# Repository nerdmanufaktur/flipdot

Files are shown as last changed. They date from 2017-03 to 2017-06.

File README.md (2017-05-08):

# flipdot
Contains Code for running the flip-dot displays based on the driver pcb both from nerdmanufaktur.berlin

## Arduino 

Copy the folders from /Arduino to your local /Arduino/libraries folder and compile/upload the /Arduino/examples example Code. (Wemos for Wifi enabled ESP8266s and Arduino_HW for everything else)

The FLIPDOT library on an ESP8266 also provides an UDP-Server that listens on Port 1234 for data. It will accept DISPLAY_WIDTH*2 byte sized frames and render them immediatly.

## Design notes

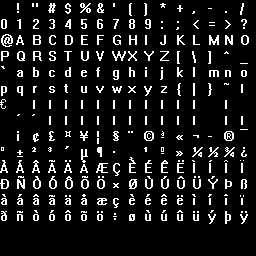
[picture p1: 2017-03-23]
font generation/ExportedFontBold.bmp

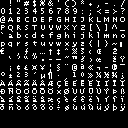
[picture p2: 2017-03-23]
font generation/ExportedFont8x8.bmp

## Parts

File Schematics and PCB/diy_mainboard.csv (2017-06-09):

Qty | Value | Device | Package | Parts | Description | DIGIKEY | MF | MPN | OC_FARNELL | OC_NEWARK
1 |  | ML34 | ML34 | SV1 | HARTING | AE11226-ND |  |  | unknown | unknown
1 |  | PINHD-1X5_2.54 | 1X05 | JP2 | PIN HEADER | A101735CT-ND
1 |  | PINHD-1X7_2.54 | 1X07 | JP1 | PIN HEADER | A101735CT-ND
1 |  | RN06 | RN-7 | RN2 | RESISTOR NETWORK | 4607X-101-472LF-ND |  |  | unknown | unknown
1 |  | W237-102 | W237-102 | X1 | WAGO SCREW CLAMP |  |  | 237-102 | unknown | 70K9898
5 | 100nF | C-EUC0603 | C0603 | C2, C4, C5, C6, C7 | CAPACITOR, European symbol | 478-5052-1-ND
2 | 100µF | CPOL-EU153CLV-0605 | 153CLV-0605 | C1, C3 | POLARIZED CAPACITOR, European symbol | 493-2203-1-ND
1 | 10k | R-EU_R0805 | R0805 | R2 | RESISTOR, European symbol | RMCF0805JT10K0CT-ND
2 | 1k | R-EU_R0805 | R0805 | R1, R3 | RESISTOR, European symbol | RMCF0805JT1K00CT-ND
3 | 74HC595D | 74HC595D | SO16 | IC2, IC3, IC4 | 8-bit SHIFT REGISTER, output latch | 568-2263-1-ND
1 | 7805DT | 7805DT | TO252 | IC1 | Positive VOLTAGE REGULATOR | MC7805CDTGOS-ND
1 | LL4148 | PMLL4150 | SOD80C | D1 | DIODE | LL4148FSCT-ND
1 | TBD62783AFGSO18 | TBD62783AFGSO18 | TBD62783AFG | U$1 |  | TBD62783AFGELCT-ND
1 | TBD62783AFGSO18 | TBD62783AFGSO18 | TBD62783AFG | U$2 |  | TBD62783AFGELCT-ND
1 | TIP131 | 2SC1306 | TO220BV | T1 | NPN Transistor Final RF Power Outupt
1 | ULN2803 | ULN2803 | TBD62783AFG | U$3 |  | 296-15777-1-ND

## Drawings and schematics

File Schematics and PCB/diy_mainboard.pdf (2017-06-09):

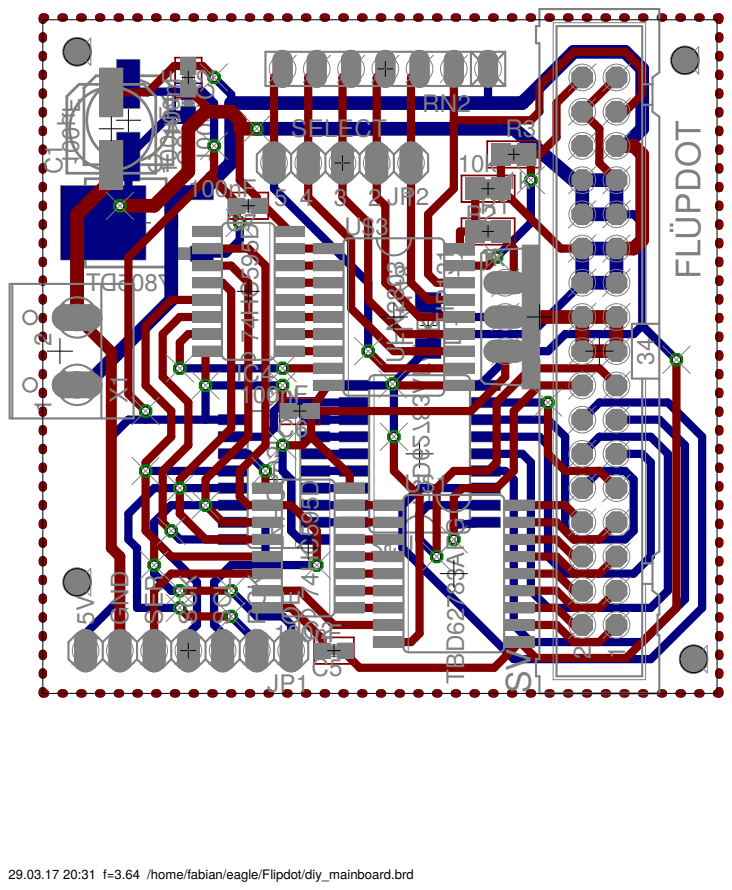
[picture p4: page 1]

29.03.17 20:31 f=3.64 /home/fabian/eagle/Flipdot/diy_mainboard.brd

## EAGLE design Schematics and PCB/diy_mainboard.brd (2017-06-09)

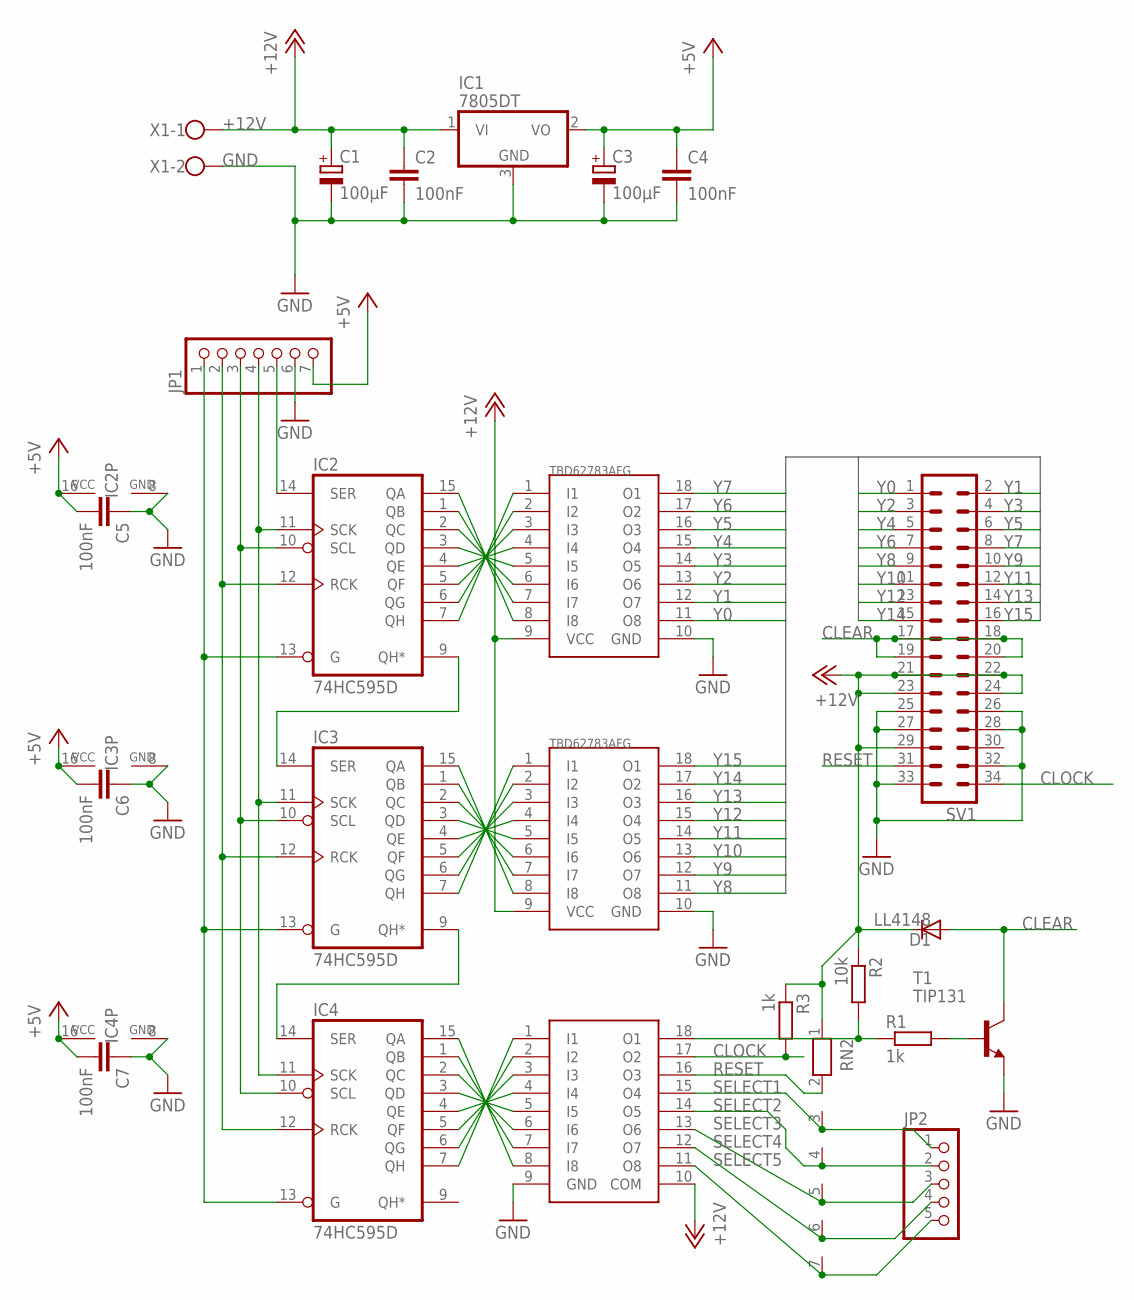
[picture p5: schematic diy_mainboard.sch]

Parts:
C1, C3: 100µF; 153CLV-0605; DIGIKEY 493-2203-1-ND
C2, C4, C5, C6, C7: 100nF; C0603; DIGIKEY 478-5052-1-ND
D1: LL4148; SOD80C; DIGIKEY LL4148FSCT-ND
IC1: 7805DT; TO252; DIGIKEY MC7805CDTGOS-ND
IC2, IC3, IC4: 74HC595D; SO16; DIGIKEY 568-2263-1-ND
JP1: PINHD-1X7; 1X07; DIGIKEY A101735CT-ND
JP2: PINHD-1X5; 1X05; DIGIKEY A101735CT-ND
R1, R3: 1k; R0805; DIGIKEY RMCF0805JT1K00CT-ND
R2: 10k; R0805; DIGIKEY RMCF0805JT10K0CT-ND
RN2: RN06; RN-7; DIGIKEY 4607X-101-472LF-ND
SV1: ML34; DIGIKEY AE11226-ND
T1: TIP131; TO220BV
U$1, U$2: TBD62783AFG; SO8-L; DIGIKEY TBD62783AFGELCT-ND
U$3: ULN2803; SO8-L; DIGIKEY 296-15777-1-ND
X1: W237-102

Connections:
+5V: C3.+, C4.1, C5.2, C6.2, C7.2, IC1.2 (VO), IC2.16 (VCC), IC3.16 (VCC), IC4.16 (VCC), JP1.7
+12V: C1.+, C2.1, D1.C, IC1.1 (VI), R2.1, R3.1, RN2.1, SV1.21, SV1.22, SV1.23, SV1.24, SV1.29, U$1.9 (VCC), U$2.9 (VCC), U$3.10 (COM), X1.1
CLEAR: D1.A, SV1.17, SV1.18, SV1.19, SV1.20, T1.2 (C)
CLOCK: R3.2, SV1.34, U$3.17 (O2)
GND: C1.-, C2.2, C3.-, C4.2, C5.1, C6.1, C7.1, IC1.3 (GND), IC2.8 (GND), IC3.8 (GND), IC4.8 (GND), JP1.6, SV1.25, SV1.26, SV1.27, SV1.28, SV1.32, SV1.33, T1.3 (E), U$1.10 (GND), U$2.10 (GND), U$3.9 (GND), X1.2
unnamed: IC2.15 (QA), U$1.8 (I8)
unnamed: IC2.1 (QB), U$1.7 (I7)
unnamed: IC2.2 (QC), U$1.6 (I6)
unnamed: IC2.3 (QD), U$1.5 (I5)
unnamed: IC2.4 (QE), U$1.4 (I4)
unnamed: IC2.5 (QF), U$1.3 (I3)
unnamed: IC2.6 (QG), U$1.2 (I2)
unnamed: IC2.7 (QH), U$1.1 (I1)
unnamed: IC3.15 (QA), U$2.8 (I8)
unnamed: IC3.1 (QB), U$2.7 (I7)
unnamed: IC3.2 (QC), U$2.6 (I6)
unnamed: IC3.3 (QD), U$2.5 (I5)
unnamed: IC3.4 (QE), U$2.4 (I4)
unnamed: IC3.5 (QF), U$2.3 (I3)
unnamed: IC3.6 (QG), U$2.2 (I2)
unnamed: IC3.7 (QH), U$2.1 (I1)
unnamed: IC2.9 (QH*), IC3.14 (SER)
unnamed: IC2.11 (SCK), IC3.11 (SCK), IC4.11 (SCK), JP1.4
unnamed: IC2.10 (SCL), IC3.10 (SCL), IC4.10 (SCL), JP1.3
unnamed: IC2.12 (RCK), IC3.12 (RCK), IC4.12 (RCK), JP1.2
unnamed: IC2.13 (G), IC3.13 (G), IC4.13 (G), JP1.1
unnamed: IC3.9 (QH*), IC4.14 (SER)
unnamed: IC4.15 (QA), U$3.8 (I8)
unnamed: IC4.1 (QB), U$3.7 (I7)
unnamed: IC4.2 (QC), U$3.6 (I6)
unnamed: IC4.3 (QD), U$3.5 (I5)
unnamed: IC4.4 (QE), U$3.4 (I4)
unnamed: IC4.5 (QF), U$3.3 (I3)
unnamed: IC4.6 (QG), U$3.2 (I2)
unnamed: IC4.7 (QH), U$3.1 (I1)
unnamed: R1.2, T1.1 (B)
unnamed: R1.1, R2.2, U$3.18 (O1)
unnamed: IC2.14 (SER), JP1.5
RESET: RN2.2, SV1.31, U$3.16 (O3)
SELECT1: JP2.1, RN2.3, U$3.15 (O4)
SELECT2: JP2.2, RN2.4, U$3.14 (O5)
SELECT3: JP2.3, RN2.5, U$3.13 (O6)
SELECT4: JP2.4, RN2.6, U$3.12 (O7)
SELECT5: JP2.5, RN2.7, U$3.11 (O8)
Y0: SV1.1, U$1.11 (O8)
Y1: SV1.2, U$1.12 (O7)
Y2: SV1.3, U$1.13 (O6)
Y3: SV1.4, U$1.14 (O5)
Y4: SV1.5, U$1.15 (O4)
Y5: SV1.6, U$1.16 (O3)
Y6: SV1.7, U$1.17 (O2)
Y7: SV1.8, U$1.18 (O1)
Y8: SV1.9, U$2.11 (O8)
Y9: SV1.10, U$2.12 (O7)
Y10: SV1.11, U$2.13 (O6)
Y11: SV1.12, U$2.14 (O5)
Y12: SV1.13, U$2.15 (O4)
Y13: SV1.14, U$2.16 (O3)
Y14: SV1.15, U$2.17 (O2)
Y15: SV1.16, U$2.18 (O1)

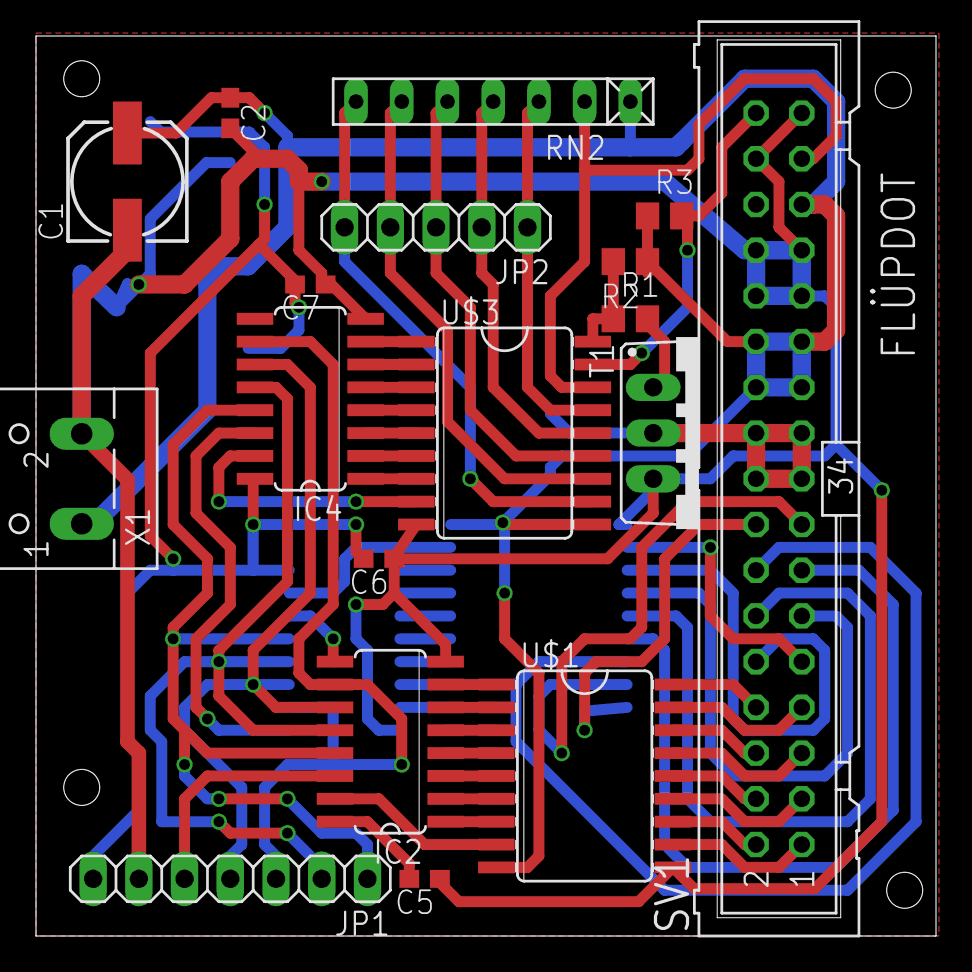
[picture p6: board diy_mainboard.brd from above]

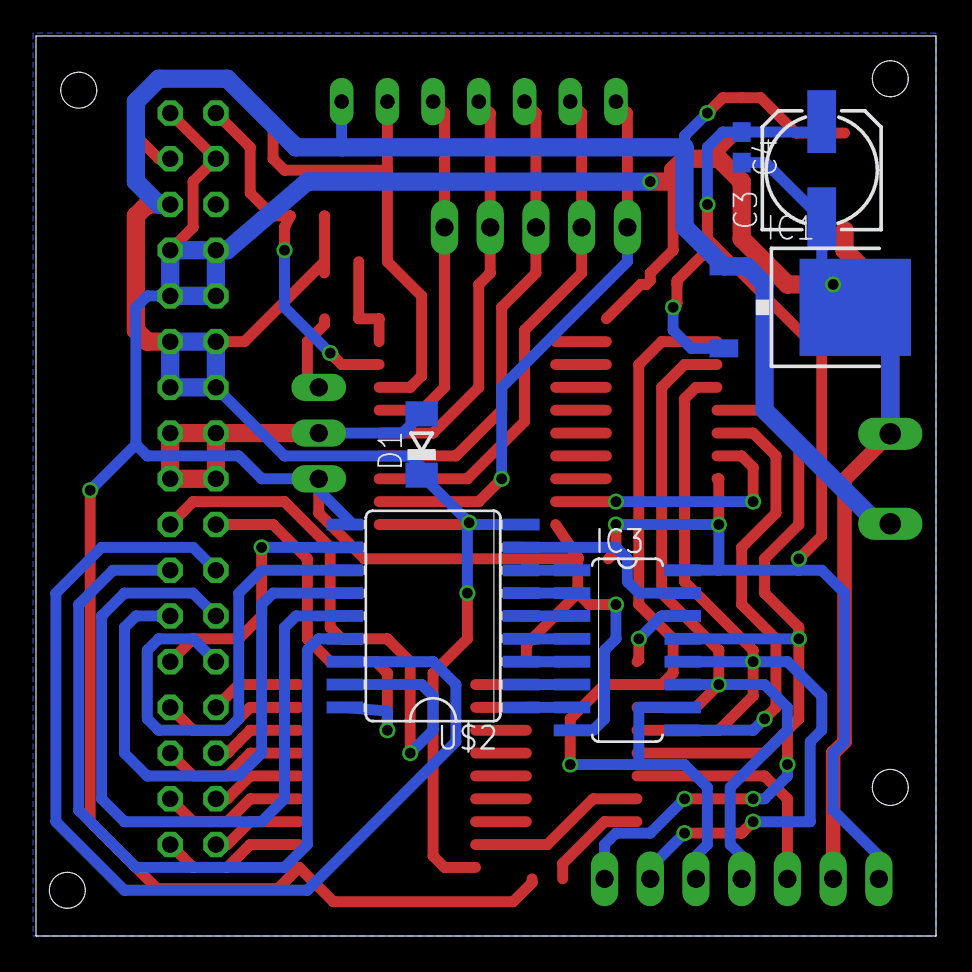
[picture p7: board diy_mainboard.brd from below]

Board: 2 copper layers, 50.0 x 50.0 mm, 24 parts (6 on the bottom side), 60 nets.

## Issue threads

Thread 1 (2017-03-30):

Arduino - Implement UDP protocol

kryptokommunist, 2017-03-30:
Add control protocol to set how long the sent frame should be rendered before displaying the next animation in main loop etc.

Options:

- display sent frame
  - display for time X
  - display forever until resume command is sent
- resume normal loop (no frame attached/to be rendered)
- pause main loop

kryptokommunist, 2017-05-08:
Done using standard library with removal of multicast function due to compiling issues

Closed 2017-05-08.

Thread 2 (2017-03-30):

Implement a snake library

kryptokommunist, 2017-03-30:
Snake with stepper function that takes in direction commands and return the current step frame

kryptokommunist, 2017-05-08:
Done @ [kryptokommunist/snake](https://github.com/kryptokommunist/snake)

Closed 2017-05-08.

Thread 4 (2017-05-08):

Improve UDP (timeout and more)

kryptokommunist, 2017-05-08:
- Implement a timeout, so the image will be displayed for a longer time until the next frame arrives (maybe around 2 secs)
- Implement UDP in a way so that it needs to be explicitly invoked, so projects without internet connection can omit this `(FLIPDOT board = FLIPDOT(); board.start_udp_server(port)`

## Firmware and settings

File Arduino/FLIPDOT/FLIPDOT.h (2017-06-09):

// - - - - -
// FLIPDOT - A Arduino library for controlling an Annex/AEG flip dot display
// FLIPDOT.cpp: Library implementation file
//
// Copyright (C) 2016 fluepke, kryptokommunist <fabian.luepke<at>student.hpi.de>,<marcus.ding<at>student.hpi.de>
// This work is licensed under a GNU style license.
//
// Last change: kryptokommunist
//
// Documentation and samples are available at https://github.com/nerdmanufaktur/flipdot
// - - - - -

// ---- Options ----
//flip screen? comment out for deactivating and vice versa
#define TURNDISPLAY_180_DEGREES

//comment out to disable debugging information via Serial
//#define DBG

#include <inttypes.h>
#include <Arduino.h>
#include <SPI.h>
#include "bitreverse_table.h"

//Arduino hw vs. ESP8266
#if defined(ESP8266)
  #include "font_non_arduino_hw.h"
  #include "font8x8_non_arduino_hw.h"
  #include <ESP8266WiFi.h>
  #include "ESPAsyncUDP.h"
  #if defined(ARDUINO_ESP8266_WEMOS_D1MINI)
    #define SHIFT_OE_PIN D2
    #define SHIFT_RCK_PIN D3
  #else
    #define SHIFT_OE_PIN 9
    #define SHIFT_RCK_PIN 3
  #endif
#else
    #include "font.h"
    #include "font8x8.h"
    #define SHIFT_OE_PIN 9
    #define SHIFT_RCK_PIN 3
#endif

#ifndef FLIPDOT_H
#define FLIPDOT_H

// ---- Constants/Preprocessor functions ----

#define UDP_PORT_FRAME_SERVER 1234

#define CHAR_WIDTH 16
#define CHAR_HEIGHT 16
#define CHAR_OFFSET CHAR_WIDTH - 6
#define CHAR_WIDTH_SMALL 8
#define CHAR_HEIGHT_SMALL 8
#define CHAR_OFFSET_SMALL CHAR_WIDTH_SMALL - 3
#define DEFAULT_SCROLL_DELAY_MILLISECONDS 0
#define DEFAULT_SCROLL_X_OFFSET DISPLAY_WIDTH
#define DEFAULT_SMALL_Y_OFFSET 4
#define RENDER_STRING_DEFAULT_X_OFFSET 0
#define DEFAULT_ZEROING_SETTING ZERO_LOCALLY

//#define PANEL_CONFIGURATION single: [1] = {25} up to full: [5] = {25,25,20,20,25}
//each entry being the width of the iths panel (either 20 or 25), change arraysize as well!
#define PANEL_CONFIGURATION [5] = {25,25,20,20,25}
#define DISPLAY_WIDTH 115 //also adjust width!

#define MAX_NUMBER_OF_PANELS 5
#define COL_HEIGHT 16

// Positions in Control Buffer
// |     7    |     6    |     5    |     4    |     3    |     2    |     1    |     0
// |  CLEAR   |   CLOCK  |   RESET  | SELECT 1 | SELECT 2 | SELECT 3 | SELECT 4 | SELECT 5 |

#define CLEAR 7
//signal is inverted
#define CLOCK 6
//signal is inverted
#define RESET 5
#define SELECT1 4
#define SELECT2 3
#define SELECT3 2
#define SELECT4 1
#define SELECT5 0

#define ALL_COLUMN_PIXELS_ON 0b1111111111111111

#if defined(DBG)
  #include <bitset>
  #define DBG_OUTPUT_PORT(data) Serial.print(data);
  #define DBG_OUTPUT_PORT_NL(data) Serial.println(data);
#else
  #define DBG_OUTPUT_PORT(data)
  #define DBG_OUTPUT_PORT_NL(data)
#endif

//sets the control bits in controlBuffer, select for all pins is 1 and for pin select_number it is set to select_value
#define setControlBits(clr,clk,rst,select_value, select_number) controlBuffer =  (clr << CLEAR) | (clk << CLOCK) | (rst << RESET) | (1 << SELECT1) | \
  (1 << SELECT2) | (1 << SELECT3) | (1 << SELECT4) | (1 << SELECT5);\
  /*catch if selected pin is set (its 0 because of inverted transistor output)*/\
  if(select_value == 0){\
      controlBuffer &=  -1 ^ (1 << select_number);\
  }

  //function call is too slow and the compiler not clever enough, therefore we use a preprocessor fake function
  #define initializePanel(select_pin)  columnBuffer = 0;\
    setControlBits(0,1,0,1,select_pin)\
    writeToRegisters();\
    digitalWrite(SHIFT_OE_PIN, LOW);\
    setControlBits(1,1,0,1,select_pin)\
    columnBuffer = ALL_COLUMN_PIXELS_ON;\
    writeToRegisters();\
    delayMicroseconds(200);\
    setControlBits(0,1,0,1,select_pin)\
    columnBuffer = 0;\
    writeToRegisters();\
    delayMicroseconds(100);\
    setControlBits(0,1,1,0,select_pin)\
    writeToRegisters();\
    delayMicroseconds(200);\
    setControlBits(1,0,1,0,select_pin)\
    writeToRegisters();\
    delayMicroseconds(20);\
    setControlBits(1,1,1,1,select_pin)\
    writeToRegisters();\
    delayMicroseconds(30);\
    setControlBits(0,1,1,1,select_pin)\
    writeToRegisters();

  //function call is too slow and the compiler not clever enough, therefore we use a preprocessor fake function
  #define writeToNewColumn(data,select_pin,time) delayMicroseconds(time);\
      setControlBits(1,1,1,1,select_pin)\
      writeToRegisters();\
      setControlBits(1,0,1,1,select_pin)\
      writeToRegisters();\
      setControlBits(1,1,1,1,select_pin)\
      columnBuffer = data;\
      writeToRegisters();\
      delayMicroseconds(time);\
      columnBuffer = 0;\
      setControlBits(0,1,1,1,select_pin)\
      writeToRegisters();\
      setControlBits(1,0,1,1,select_pin)\
      writeToRegisters();\
      setControlBits(1,1,1,1,select_pin)\
      writeToRegisters();\
      setControlBits(0,1,1,1,select_pin)\
      writeToRegisters();

// ---- Methods ----

class FLIPDOT {

public:
  //ZERO_ALL => zero the entire buffer before rendering
  //ZERO_LOCALLY => zero the entire column if something is rendered on it, leave remaining columns as before
  //ZERO_NONE => don't zero anything, just merge the previous pixel state with the additional pixels
  typedef enum { ZERO_ALL,ZERO_LOCALLY,ZERO_NONE } ZeroOptions;
  typedef enum { NONE, STEP_THROUGH_PIXEL_CHANGES } Animation;
  FLIPDOT();
  void init();
  void render_frame(uint16_t frame[DISPLAY_WIDTH]);
  void render_to_panel(uint16_t* frame, uint8_t panel_index);
  void render_string(const char *s, int x_offset = RENDER_STRING_DEFAULT_X_OFFSET, ZeroOptions zero_buffer = DEFAULT_ZEROING_SETTING);
  void render_string_small(const char* str, int x_offset = RENDER_STRING_DEFAULT_X_OFFSET, short y_offset = DEFAULT_SMALL_Y_OFFSET, ZeroOptions zero_buffer = DEFAULT_ZEROING_SETTING);
  void scroll_string(const char *s, int x_offset = DEFAULT_SCROLL_X_OFFSET, int millis_delay = DEFAULT_SCROLL_DELAY_MILLISECONDS, ZeroOptions zero_buffer = DEFAULT_ZEROING_SETTING);
  void scroll_string_small(const char *s, int x_offset = DEFAULT_SCROLL_X_OFFSET, int millis_delay = DEFAULT_SCROLL_DELAY_MILLISECONDS, short y_offset = DEFAULT_SMALL_Y_OFFSET, ZeroOptions zero_buffer = DEFAULT_ZEROING_SETTING);
  void render_char_to_buffer(char c, short x, ZeroOptions zero_buffer);
  void render_char_to_buffer_small(char c, int x, short y_offset, ZeroOptions zero_buffer);
  void merge_columns(uint16_t* dest_column, const uint16_t* src_column) ;
  void render_internal_framebuffer();
  void render_internal_framebuffer_diff_step_animation();
  void draw_in_internal_framebuffer(int val, uint8_t x, uint8_t y);
  void draw_byte_in_internal_framebuffer(uint8_t val, uint8_t x, uint8_t y);
  void all_off();
  void all_on();
  void start_udp_server();
  void stop_udp_server();
  bool received_udp_frame_recently();
  void reset_internal_framebuffer();
  uint8_t read_internal_framebuffer(uint8_t x, uint8_t y);
  uint8_t get_panel_column_offset(uint8_t panel_index);
private:
  uint8_t panel_configuration PANEL_CONFIGURATION;
  uint8_t select_pin_mapping[MAX_NUMBER_OF_PANELS] = {SELECT1,SELECT2,SELECT3,SELECT4,SELECT5};
  uint8_t number_of_panels;
  uint16_t frame_buff[DISPLAY_WIDTH] = {0}; //frame buffer (for super fancy diffing etc.)
  uint16_t last_frame_buff[DISPLAY_WIDTH] = {0};
  uint16_t columnBuffer = 0; //holds data of current column pixel data
  byte controlBuffer = 0; //holds data of current control bits (clear, clock, reset, select 1, ... , select 5)
  bool col_changed[DISPLAY_WIDTH] = {false}; //indicates if column changed since last rendering
  void writeToRegisters();
  void render_frame_no_yield(uint16_t frame[DISPLAY_WIDTH]);
  void render_internal_framebuffer_no_yield();
  void set_frame_buff(int val);
  bool frame_buff_changed_for_panel(uint8_t panel_index);
  uint16_t font_column_rendering_convert_endianess(uint16_t current_font_column, short y_offset);

  //only for esp8266
  #if defined(ESP8266)
    AsyncUDP udp;
    long time_since_last_udp_frame;
    void process_udp_frame(uint8_t* data, size_t length);
  #endif
};

#endif

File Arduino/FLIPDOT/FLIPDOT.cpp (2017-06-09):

// - - - - -
// FLIPDOT - A Arduino library for controlling an Annex/AEG flip dot display
// FLIPDOT.cpp: Library implementation file
//
// Copyright (C) 2016 fluepke, kryptokommunist <fabian.luepke<at>student.hpi.de>,<marcus.ding<at>student.hpi.de>
// This work is licensed under a GNU style license.
//
// Last change: kryptokommunist
//
// Documentation and samples are available at https://github.com/nerdmanufaktur/flipdot
// - - - - -

/* ----- LIBRARIES ----- */
#include "FLIPDOT.h"

/*
Initialize to set the pin mapping as described above
*/
FLIPDOT::FLIPDOT() {
  pinMode(SHIFT_RCK_PIN, OUTPUT);
  pinMode(SHIFT_OE_PIN, OUTPUT);
  digitalWrite(SHIFT_OE_PIN, LOW); // output shift register values
  number_of_panels = sizeof(panel_configuration)/sizeof(panel_configuration[0]);
  DBG_OUTPUT_PORT("Created FLIPDOT. Calculated no of panels: ")
  DBG_OUTPUT_PORT_NL(number_of_panels)
}

/*
Initialize all pins and getting the SPI ready to rock!
*/
void FLIPDOT::init() {
  SPI.begin();
  SPI.setDataMode(SPI_MODE0);
  SPI.setBitOrder(MSBFIRST);
  SPI.setClockDivider(SPI_CLOCK_DIV2);
}

/*
Write current control and column buffers via SPI to shift registers
*/
void FLIPDOT::writeToRegisters() {
  SPI.transfer(controlBuffer);
  #if defined(_ESP8266_SPIFAST)
  		SPI.write16(columnBuffer);
  #else
  		#if defined(_SPI_MULTITRANSFER)
  		    //last version of ESP8266 for arduino support this
  		    uint8_t pattern[2] = { (uint8_t)(c >> 8), (uint8_t)(c >> 0) };
  		    SPI.writePattern(pattern, 2, (uint8_t)1);
  		#else
  			 SPI.transfer(columnBuffer >> 8);
         SPI.transfer(columnBuffer >> 0);
      #endif
  #endif
  digitalWrite(SHIFT_RCK_PIN, HIGH);
  digitalWrite(SHIFT_RCK_PIN, LOW);
}

/*
Render a frame on the board
*/
void FLIPDOT::render_frame(uint16_t frame[DISPLAY_WIDTH]) {
    for(uint8_t i = 0; i < number_of_panels; i++){
        if(frame_buff_changed_for_panel(i)){
            render_to_panel(frame, i);
            //only for esp8266, give it time to do fancy networking stuff
            #if defined(ESP8266)
              yield();
            #endif
        }
    }
}

/*
Render a frame on the board without using yield to avoid exceptions when the heap is full
*/
void FLIPDOT::render_frame_no_yield(uint16_t frame[DISPLAY_WIDTH]) {
    for(uint8_t i = 0; i < number_of_panels; i++){
        if(frame_buff_changed_for_panel(i)){
            render_to_panel(frame, i);
        }
    }
}

/*
Render internal frame buffer on the board without using yield to avoid exceptions when the heap is full
*/
void FLIPDOT::render_internal_framebuffer_no_yield() {
      render_frame_no_yield(frame_buff);
}

/*
Render a frame from given buffer to specified panel
*/
void FLIPDOT::render_to_panel(uint16_t* frame, uint8_t panel_index) {
    const uint8_t pin = select_pin_mapping[panel_index];
    const uint8_t col_start = get_panel_column_offset(panel_index);
    //preprocessor function!
    initializePanel(pin)

    #if defined(TURNDISPLAY_180_DEGREES)
    for (int current_col = col_start + panel_configuration[panel_index]-1; current_col >= col_start; current_col -= 1) {
        uint8_t a = frame[current_col];
        uint8_t b = frame[current_col] >> 8;
        uint16_t col = BitReverseTable256[a] << 8 | BitReverseTable256[b] << 0;
    #else
    for (uint8_t current_col = col_start; current_col < col_start + panel_configuration[panel_index]; current_col++) {
        uint16_t col = frame[current_col];
    #endif
        DBG_OUTPUT_PORT_NL(std::bitset<16>(col).to_string().c_str());
        DBG_OUTPUT_PORT("Index current_col: ")
        DBG_OUTPUT_PORT_NL(current_col)
        if(col_changed[current_col]){
          writeToNewColumn(col, pin, 800) //give the spools time to flip!
        } else {
          writeToNewColumn(col, pin, 10) //no change => no time needed
        }
    }
    DBG_OUTPUT_PORT_NL()
}

/*
Render internal frame buffer on the board
*/
void FLIPDOT::render_internal_framebuffer() {
      render_frame(frame_buff);
}

/*
Render internal frame buffer on the board with a animation stepping through every changed pixel one by one
*/
void FLIPDOT::render_internal_framebuffer_diff_step_animation() {
      /*
        TO-DO: Implement for different patterns not just upper left to lower right;
      */
      render_frame(frame_buff);
      for(int x = 0; x < DISPLAY_WIDTH; x++){
        uint16_t current_col = frame_buff[x];
        uint16_t last_col = last_frame_buff[x];
        if(current_col != last_col){
          for(int y = 0; y < 16; y++){
            uint8_t bit_mask = 1 << y;
            uint8_t current_col_bit = current_col & bit_mask;
            if (current_col_bit != (last_col & bit_mask)) {
              draw_in_internal_framebuffer(current_col_bit,x,y);
              render_internal_framebuffer();
            }
          }
        }
      }
}


/*
Merges two given columns into the dest_column
*/
void FLIPDOT::merge_columns(uint16_t* dest_column, const uint16_t* src_column) {
  *dest_column |= *src_column;
}

/*
Render a char to the frame_buff with horizontal offset (can be negative)
*/
void FLIPDOT::render_char_to_buffer(char c, short x_offset, ZeroOptions zero_buffer) {
  // Convert the character to an index
  c = (c - 32);
  uint16_t current_font_column;
  short current_pos;
  // Draw pixels
  for (uint8_t j=0; j<CHAR_WIDTH; j++) {
    current_pos = x_offset+j;
    if((current_pos >= 0) && (current_pos < DISPLAY_WIDTH)) { //case of negative offset
      current_font_column = pgm_read_word_near(font + c*CHAR_WIDTH + j); //returns uint16_t in big endian
      if(zero_buffer == ZERO_ALL || zero_buffer == ZERO_LOCALLY){
        frame_buff[current_pos] = current_font_column;
      } else {
        merge_columns(&frame_buff[current_pos],&current_font_column);
      }
    }
  }
}
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

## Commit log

2017-03-23 improve perfomance of FLIPDOT::scroll_string()
    [FLIPDOT.cpp]
2017-03-23 add FLIPDOT::all_off() and FLIPDOT::render_internal_framebuffer() and perfomance improvements
    [FLIPDOT.cpp, FLIPDOT.h]
2017-03-25 add support for up to 5 display boards
2017-03-25 add functionality of rendering multiple strings on board
2017-03-28 update README and Arduino code
2017-03-29 add asynchronous UDP server to receive frames over network
2017-03-29 now really adding asynchronous UDP server to receive frames over network
2017-03-30 fix exception due to calling yield when heap is full
    [FLIPDOT.cpp, FLIPDOT.h]
2017-03-30 split examples into esp8266 and non wifi Arduino hw
2017-03-30 fix bug with correctly detecting usage of ESP8266
    [Arduino_HW.ino, FLIPDOT.cpp, FLIPDOT.h]
2017-03-30 fix bug concerning usage of other boards than wemos
    [FLIPDOT.h]
2017-04-03 Added schematics and pcb layout
    [diy_mainboard.GBL, diy_mainboard.GBO, diy_mainboard.GBP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]
2017-05-08 Fix bugs and add better demo program
    [ESPTime.cpp, FLIPDOT.cpp, FLIPDOT.h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]
2017-05-08 Fix Syntax issues + Edit travis.yml
    [Wemos.ino, Wemos_Demo.ino]
2017-06-01 Massive speed increase by skipping unchanged columns
    [ESPTime.cpp, FLIPDOT.cpp, FLIPDOT.h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]
